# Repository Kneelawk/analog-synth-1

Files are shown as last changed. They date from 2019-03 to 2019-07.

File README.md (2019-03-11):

# analog-synth-1
A simple 1v/oct synth using op-amps

This project is a version of the 1v/oct synth from [DIY Synth Series Part 1 - The Exponential VCO](https://www.allaboutcircuits.com/projects/diy-synth-series-vco/) modified to use the TL084 and to fit into a 12hp module.

In addition this module has a multicolor LED that lights depending on the CV and GATE values.

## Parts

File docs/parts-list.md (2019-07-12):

# Parts List

Some of the parts contained within this project have specific suppliers and specifications.
Here are some of those parts:

* [LED_RCBG](#led_rcbg)
* [PJ398SM](#pj398sm)
* [Conn_02x08_Odd_Even](#conn_02x08_odd_even)

# Part Specifications

## LED_RCBG
Mouser Product URL:
https://www.mouser.com/ProductDetail/Kingbright/WP154A4SUREQBFZGW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

Manufacturer: Kingbright

Datasheet URL:
https://www.mouser.com/datasheet/2/216/WP154A4SUREQBFZGW-67444.pdf

## PJ398SM
### Product Notes
The PJ301M-12 is being discontinued due to some design flaws. Its replacement is the PJ398SM.
The PJ301M-12 has the same footprint as the PJ398SM.

### URLs
Product URL:
https://www.thonk.co.uk/shop/thonkiconn/

## Conn_02x08_Odd_Even
### Product Notes
This jack is the 16-pin shrouded eurorack header.

### URLS
Product URL:
https://store.synthrotek.com/16-Pin_Keyed_Shrouded_Eurorack_Power_Header

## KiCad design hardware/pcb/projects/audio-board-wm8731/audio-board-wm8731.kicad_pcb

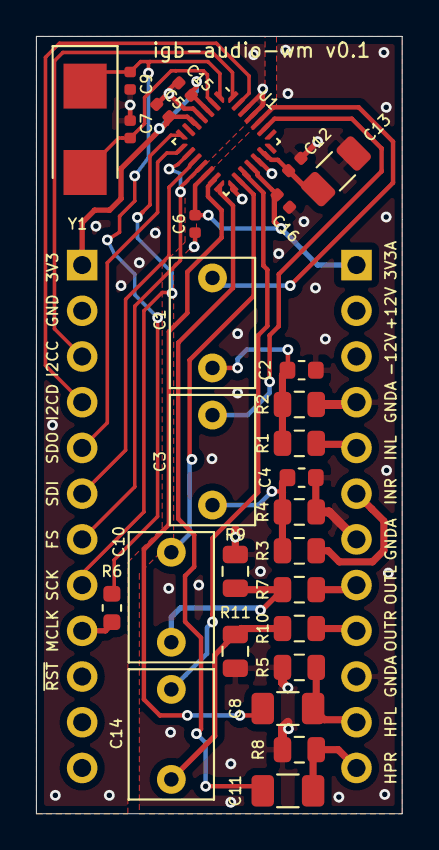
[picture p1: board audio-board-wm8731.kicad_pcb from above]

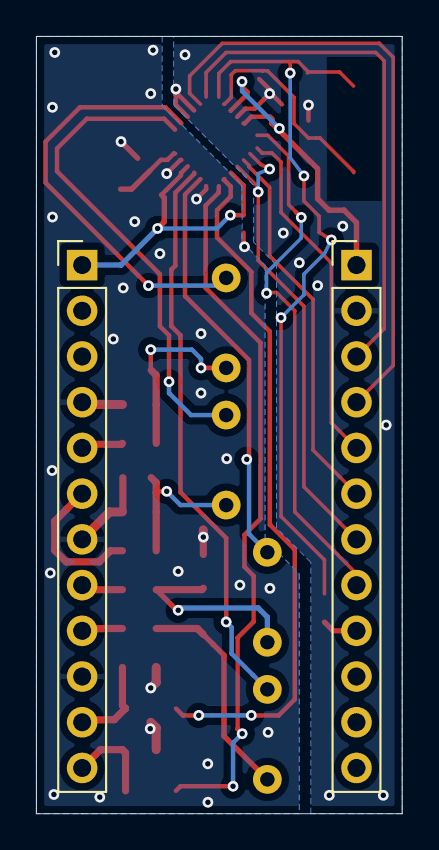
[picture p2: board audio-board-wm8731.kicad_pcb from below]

Board: 2 copper layers, 20.3 x 43.2 mm, 31 parts (2 on the bottom side), 30 nets.

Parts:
C1, C3, C10, C14: 1u; C_Rect_L7.0mm_W4.5mm_P5.00mm
C2, C4: 220p; C_0603_1608Metric
C5, C6, C12, C15, C16: 100n; C_0402_1005Metric
C7, C9: 18p; C_0402_1005Metric
C8, C11: 100u; C_1206_3216Metric
C13: 10u; C_1206_3216Metric
J1, J2: Conn_01x12; PinHeader_1x12_P2.54mm_Vertical
R1, R2, R3, R4: 10k; R_0805_2012Metric
R5, R8, R9, R11: 100k; R_0805_2012Metric
R6: 0; R_0603_1608Metric
R7, R10: 100; R_0805_2012Metric
U1: wm8731_qfn; QFN-28_4x4mm_P0.5mm
Y1: 12.288MHz; Crystal_SMD_Abracon_ABM3-2pin_5.0x3.2mm_hand

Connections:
+3.3VA: C6.2, C16.2, J1.1, U1.12, U1.18
+3V3: C5.2, C15.2, J2.1, U1.3, U1.5
/ADC_L: C1.2, U1.24
/ADC_R: C3.2, U1.23
/DAC_L: C10.2, U1.16
/DAC_R: C14.2, U1.17
/HP_OUT_L: C8.2, J1.11, R5.2
/HP_OUT_R: C11.2, J1.12, R8.2
/I2C_SCL: J2.3, U1.28
/I2C_SDA: J2.4, U1.27
/I2S_FS: J2.7, U1.9, U1.11
/I2S_MCLK: J2.9, R6.1
/I2S_SCK: J2.8, U1.7
/I2S_SDI: J2.6, U1.10
/I2S_SDO: J2.5, U1.8
/LINE_IN_L: J1.5, R1.2
/LINE_IN_R: J1.6, R3.2
/LINE_OUT_L: J1.8, R7.2
/LINE_OUT_R: J1.9, R10.2
GND: C5.1, C7.2, C9.2, C15.1, J2.2, U1.4, U1.25, U1.26
GNDA: C2.1, C4.1, C6.1, C12.2, C13.2, C16.1, J1.4, J1.7, J1.10, R2.2, R4.2, R5.1, R8.1, R9.1, R11.1, U1.15, U1.19
unnamed: C1.1, C2.2, R1.1, R2.1
unnamed: C3.1, C4.2, R3.1, R4.1
unnamed: C7.1, U1.2, Y1.2
unnamed: C8.1, U1.13
unnamed: C9.1, R6.2, U1.1, Y1.1
unnamed: C10.1, R7.1, R9.2
unnamed: C11.1, U1.14
unnamed: C12.1, C13.1, U1.20
unnamed: C14.1, R10.1, R11.2

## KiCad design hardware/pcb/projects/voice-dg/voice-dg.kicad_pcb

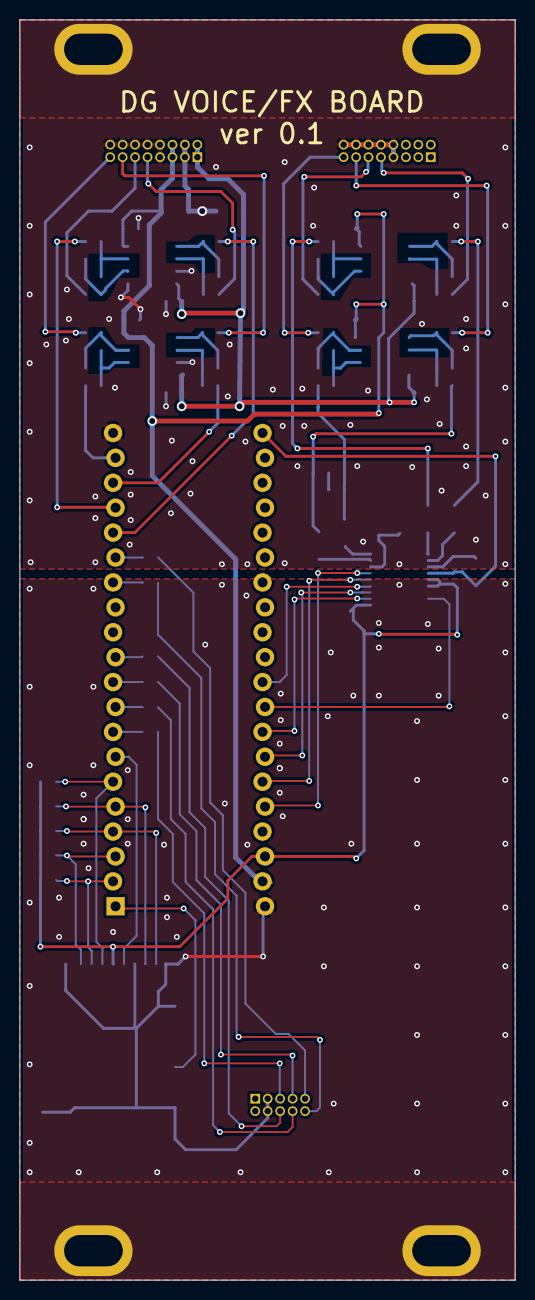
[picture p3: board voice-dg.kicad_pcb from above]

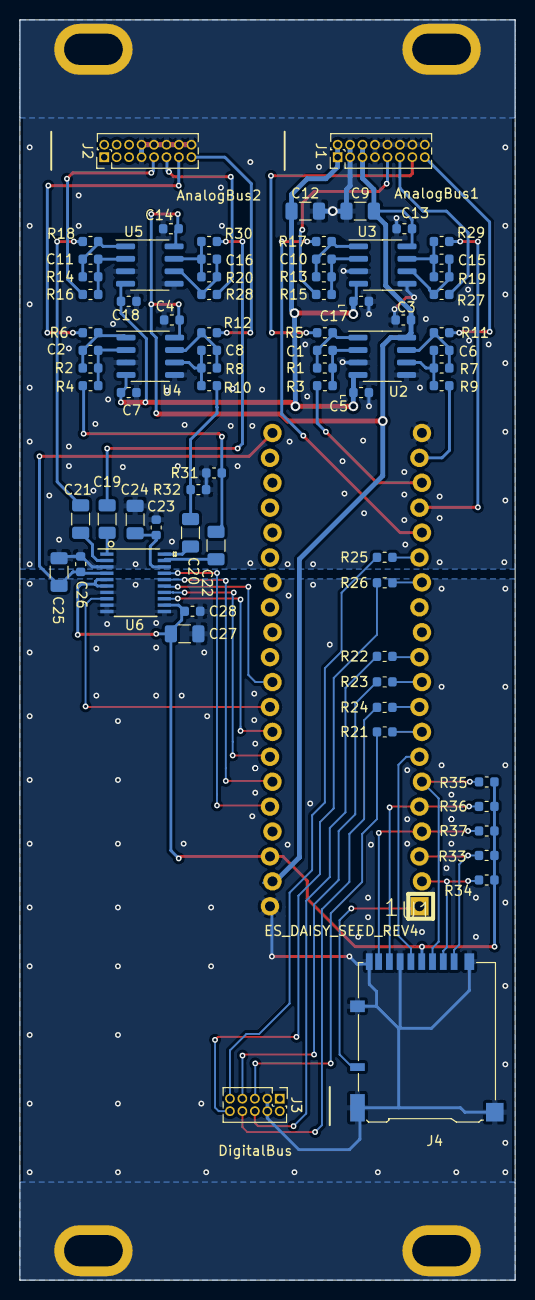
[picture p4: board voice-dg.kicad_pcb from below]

Board: 2 copper layers, 50.5 x 128.5 mm, 75 parts (75 on the bottom side), 68 nets.

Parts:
C1, C2, C6, C8, C10, C11, C15, C16: 12p; C_0603_1608Metric
C3, C4, C5, C7, C13, C14, C17, C18, C23, C26, C28: 100n; C_0603_1608Metric
C9, C12: 22u; C_1206_3216Metric
C19, C20, C21, C22, C25, C27: 10u; C_1206_3216Metric
C24: 2.2u; C_1206_3216Metric
J1: AnalogBus; PinHeader_2x08_P1.27mm_Vertical
J2: AnalogBusEx; PinHeader_2x08_P1.27mm_Vertical
J3: DigitalBus; PinHeader_2x05_P1.27mm_Vertical
J4: Micro_SD_Card_Det_Hirose_DM3AT; microSD_HC_Hirose_DM3AT-SF-PEJM5_hand
R1, R2, R7, R8, R15, R16, R27, R28: 100k; R_0603_1608Metric
R3, R4, R9, R10, R13, R14, R19, R20: 10k; R_0603_1608Metric
R5, R6, R11, R12, R17, R18, R29, R30: 470; R_0603_1608Metric
R21, R22, R23, R24, R25, R26: 47; R_0603_1608Metric
R31, R32, R33, R34, R35, R36, R37: 47k; R_0603_1608Metric
U1: ES_DAISY_SEED_REV4; ES_DAISY_SEED
U2, U3, U4, U5: OPA2134; SOIC-8_3.9x4.9mm_P1.27mm
U6: AK4556VT

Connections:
+3.3VA: C25.2, C26.1, U1.21, U6.4
+3V3: C27.2, C28.1, J4.4, R33.2, R34.2, R35.2, R36.2, R37.2, U1.38, U6.5, U6.6, U6.12
+12V: C3.1, C4.1, C9.2, C13.1, C14.1, J1.5, J1.6, U1.39, U2.8, U3.8, U4.8, U5.8
-12V: C5.1, C7.1, C12.1, C17.1, C18.1, J1.1, J1.2, U2.4, U3.4, U4.4, U5.4
/AK4556_RST: U1.36, U6.17
/AnalogIn1: J1.9, R15.2
/AnalogIn2: J1.11, R27.2
/AnalogIn3: J2.9, R16.2
/AnalogIn4: J2.11, R28.2
/AnalogOut1: J1.13, R5.1
/AnalogOut2: J1.15, R11.1
/AnalogOut3: J2.13, R6.1
/AnalogOut4: J2.15, R12.1
/DG_AUDIO_IN_L: R17.1, U1.16
/DG_AUDIO_IN_R: R29.1, U1.17
/DG_AUDIO_OUT_L: R3.2, U1.18
/DG_AUDIO_OUT_R: R9.2, U1.19
/EX_AUDIO_IN_L: C21.1, R18.1
/EX_AUDIO_IN_R: C19.1, R30.1
/EX_AUDIO_OUT_L: C22.2, R4.2, R31.2
/EX_AUDIO_OUT_R: C20.2, R10.2, R32.2
/SAI2_FS_B: U1.34, U6.14
/SAI2_MCLK_B: U1.31, U6.15
/SAI2_SCK_B: U1.35, U6.16
/SAI2_SD_A: U1.33, U6.13
/SAI2_SD_B: U1.32, U6.8
/SD_CLK: J4.5, U1.7
/SD_CMD: J4.3, R35.1, U1.6
/SD_D0: J4.7, R36.1, U1.5
/SD_D1: J4.8, R37.1, U1.4
/SD_D2: J4.1, R33.1, U1.3
/SD_D3: J4.2, R34.1, U1.2
/SPI_MISO: R23.2, U1.10
/SPI_MOSI: R22.1, U1.11
/SPI_SCK: R24.1, U1.9
/USART_RX: R25.2, U1.15
/USART_TX: R26.1, U1.14
/~SD_SW: J4.10, U1.1
/~SPI_CS: R21.2, U1.8
GND: C27.1, C28.2, J3.3, J3.4, J4.6, J4.9, J4.11, U1.40, U6.7, U6.9, U6.10, U6.11
GNDA: C3.2, C4.2, C5.2, C7.2, C9.1, C12.2, C13.2, C14.2, C17.2, C18.2, C23.2, C24.1, C25.1, C26.2, J1.3, J1.4, J1.7, J1.8, J1.10, J1.12, J1.14, J1.16, J2.7, J2.8, J2.10, J2.12, J2.14, J2.16, R31.1, R32.1, U1.20, U2.3, U2.5, U3.3, U3.5, U4.3, U4.5, U5.3, U5.5, U6.3
unnamed: C1.1, R1.1, R5.2, U2.1
unnamed: C1.2, R1.2, R3.1, U2.2
unnamed: C2.1, R2.1, R6.2, U4.1
unnamed: C2.2, R2.2, R4.1, U4.2
unnamed: C6.1, R7.1, R11.2, U2.7
unnamed: C6.2, R7.2, R9.1, U2.6
unnamed: C8.1, R8.1, R12.2, U4.7
unnamed: C8.2, R8.2, R10.1, U4.6
unnamed: C10.1, R13.1, R17.2, U3.1
unnamed: C10.2, R13.2, R15.1, U3.2
unnamed: C11.1, R14.1, R18.2, U5.1
unnamed: C11.2, R14.2, R16.1, U5.2
unnamed: C15.1, R19.1, R29.2, U3.7
unnamed: C15.2, R19.2, R27.1, U3.6
unnamed: C16.1, R20.1, R30.2, U5.7
unnamed: C16.2, R20.2, R28.1, U5.6
unnamed: C19.2, U6.1
unnamed: C20.1, U6.20
unnamed: C21.2, U6.2
unnamed: C22.1, U6.19
unnamed: C23.1, C24.2, U6.18
unnamed: J3.5, R21.1
unnamed: J3.6, R22.2
unnamed: J3.7, R23.1
unnamed: J3.8, R24.2
unnamed: J3.9, R25.1
unnamed: J3.10, R26.2

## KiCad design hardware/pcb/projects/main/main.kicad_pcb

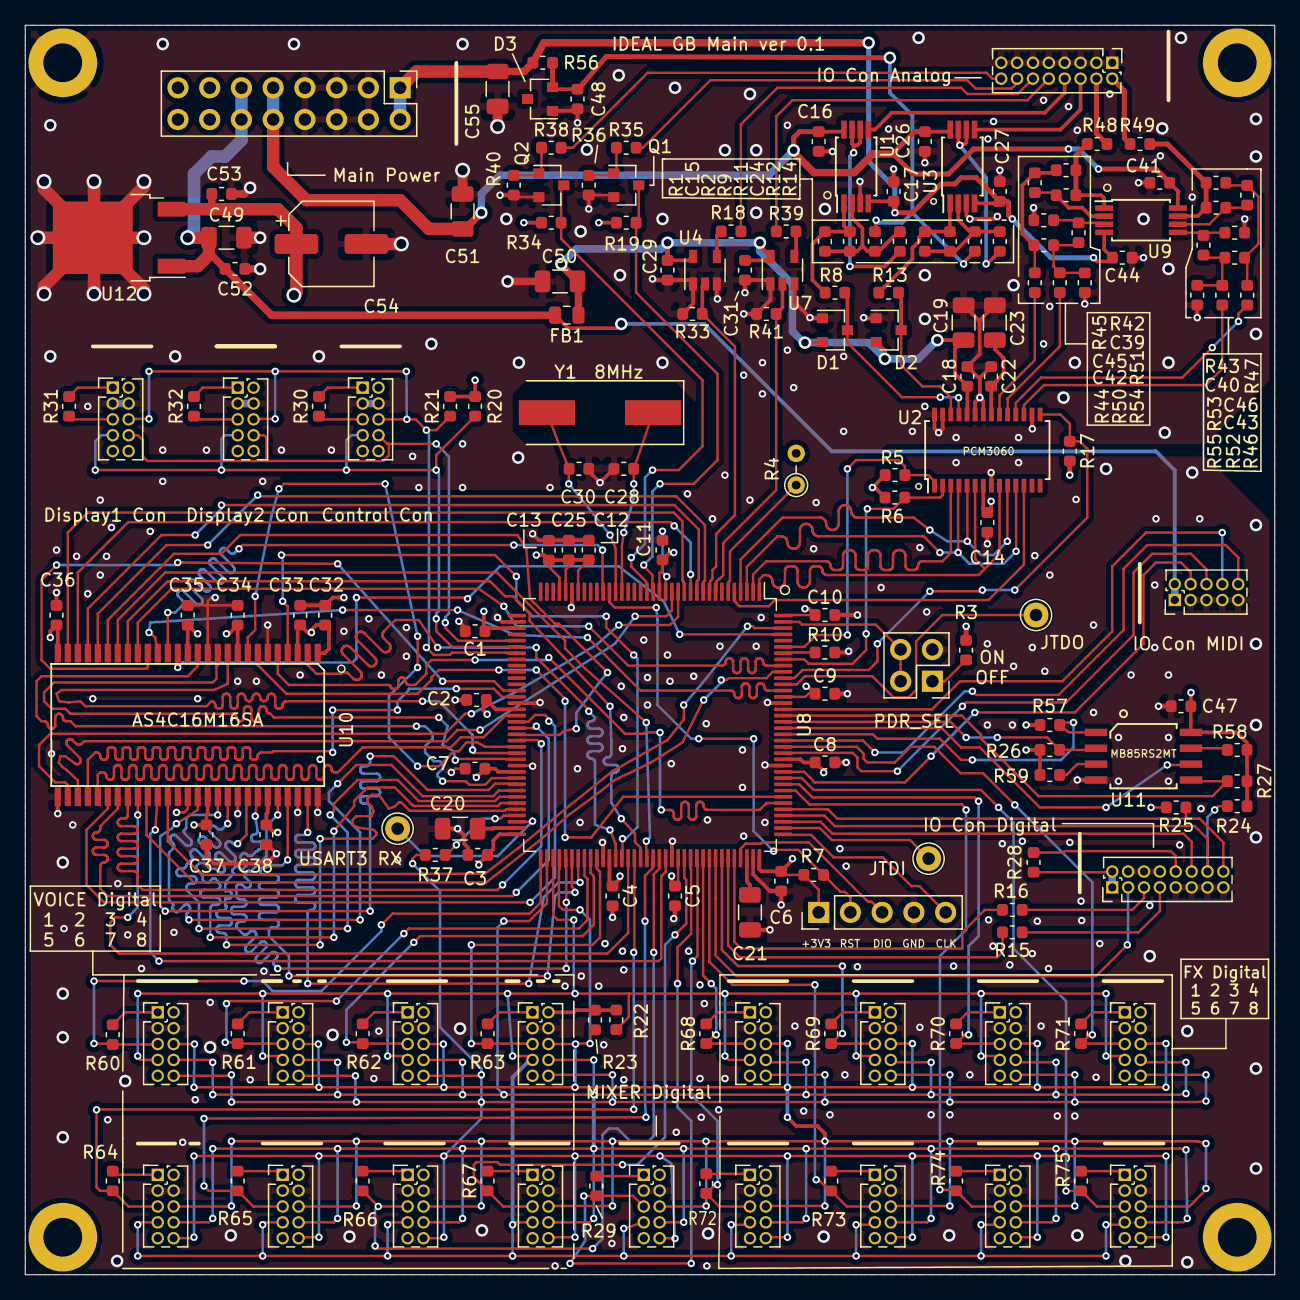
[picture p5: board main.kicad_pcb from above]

Board: 4 copper layers, 100.0 x 100.0 mm, 176 parts (0 on the bottom side), 154 nets.

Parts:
C1, C2, C3, C4, C5, C6, C7, C8, C9, C10, C11, C12, C13, C14, C16, C17, C18, C22, C25, C26, C27, C29, C31, C32, C33, C34, C35, C36, C37, C38, C41, C44, C47, C48, C52, C53: 100n; C_0603_1608Metric
C15, C24, C28, C30: 18p; C_0603_1608Metric
C19, C23: 10u; C_1206_3216Metric
C20, C21: 2.2u; C_1206_3216Metric
C39, C40, C45, C46: 470p; C_0603_1608Metric
C42, C43: 2.2n; C_0603_1608Metric
C49, C50, C51, C55: 22u; C_1206_3216Metric
C54: 100u; CP_Elec_6.3x5.3
D1, D2: BAT54S; SOT-23
D3: LM4040; SOT-23
FB1: Ferrite; R_0805_2012Metric
J1: IO_CON_ANALOG; PinHeader_2x08_P1.27mm_Vertical
J2: PDR_ON_SEL; PinHeader_2x02_P2.54mm_Vertical
J3: VOICE1_DIGITAL; PinHeader_2x05_P1.27mm_Vertical
J4: FX1_DIGITAL; PinHeader_2x05_P1.27mm_Vertical
J5: VOICE5_DIGITAL; PinHeader_2x05_P1.27mm_Vertical
J6: FX5_DIGITAL; PinHeader_2x05_P1.27mm_Vertical
J7: VOICE2_DIGITAL; PinHeader_2x05_P1.27mm_Vertical
J8: FX2_DIGITAL; PinHeader_2x05_P1.27mm_Vertical
J9: VOICE6_DIGITAL; PinHeader_2x05_P1.27mm_Vertical
J10: FX6_DIGITAL; PinHeader_2x05_P1.27mm_Vertical
J11: VOICE3_DIGITAL; PinHeader_2x05_P1.27mm_Vertical
J12: FX3_DIGITAL; PinHeader_2x05_P1.27mm_Vertical
J13: VOICE7_DIGITAL; PinHeader_2x05_P1.27mm_Vertical
J14: FX7_DIGITAL; PinHeader_2x05_P1.27mm_Vertical
J15: IO_CON_MIDI; PinHeader_2x05_P1.27mm_Vertical
J16: VOICE4_DIGITAL; PinHeader_2x05_P1.27mm_Vertical
J17: FX4_DIGITAL; PinHeader_2x05_P1.27mm_Vertical
J18: VOICE8_DIGITAL; PinHeader_2x05_P1.27mm_Vertical
J19: FX8_DIGITAL; PinHeader_2x05_P1.27mm_Vertical
J20: SWD_CON; PinHeader_1x05_P2.54mm_Vertical
J21: MIXER_DIGITAL; PinHeader_2x05_P1.27mm_Vertical
J22: DISPLAY1_DIGITAL; PinHeader_2x05_P1.27mm_Vertical
J23: IO_CON_DIGITAL; PinHeader_2x08_P1.27mm_Vertical
J24: POWER_CON; PinHeader_2x08_P2.54mm_Vertical
J25: CONTROL_DIGTAL; PinHeader_2x05_P1.27mm_Vertical
J26: DISPLAY2_DIGITAL; PinHeader_2x05_P1.27mm_Vertical
Q1, Q2: MMBT3904; SOT-23
R1, R11: 30k; R_0603_1608Metric
R2, R12: 120k; R_0603_1608Metric
R3, R5, R6, R7, R10, R17, R19, R20, R21, R22, R23, R24, R25, R26, R27, R28, R29, R30, R31, R32, R33, R34, R41, R57, R58, R59, R60, R61, R62, R63, R64, R65, R66, R67, R68, R69, R70, R71, R72, R73, R74, R75: 10k; R_0603_1608Metric
R4: 0; R_Axial_DIN0204_L3.6mm_D1.6mm_P2.54mm_Vertical
R8, R13, R48, R49: 470; R_0603_1608Metric
R9, R14: 200k; R_0603_1608Metric
R15, R16, R37: 10; R_0603_1608Metric
R18, R39, R45, R47, R51, R53: 1k; R_0603_1608Metric
R35, R36, R38, R40: 100k; R_0603_1608Metric
R42, R43, R54, R55: 12k; R_0603_1608Metric
R44, R46, R50, R52: 4.7k; R_0603_1608Metric
R56: 3.3k; R_0603_1608Metric
TP1: JTDI; Pin_D1.0mm_L10.0mm
TP2: JTDO; Pin_D1.0mm_L10.0mm
TP3: USART3_RX; Pin_D1.0mm_L10.0mm
U1, U3, U9: TL072; TSSOP-8_4.4x3mm_P0.65mm
U2: PCM3060; TSSOP-28_4.4x9.7mm_P0.65mm
U4, U7: 74AHCT1G125; SOT-23-5
U8: STM32F446ZETx; LQFP-144_20x20mm_P0.5mm
U10: AS4C16M16SA
U11: MB85RS2MT
U12: L7803; TO-252-2
Y1: 8MHz; Crystal_SMD_HC49-SD

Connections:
+3V3: C1.1, C2.1, C3.1, C4.1, C5.1, C6.1, C7.1, C8.1, C9.1, C10.1, C11.1, C12.1, C13.1, C14.1, C25.1, C32.1, C33.1, C34.1, C35.1, C36.1, C37.1, C38.1, C47.2, C53.1, C54.1, J3.1, J3.2, J4.1, J4.2, J5.1, J5.2, J6.1, J6.2, J7.1, J7.2, J8.1, J8.2, J9.1, J9.2, J10.1, J10.2, J11.1, J11.2, J12.1, J12.2, J13.1, J13.2, J14.1, J14.2, J16.1, J16.2, J17.1, J17.2, J18.1, J18.2, J19.1, J19.2, J20.1, J21.1, J21.2, J22.1, J22.2, J23.1, J23.2, J25.1, J25.2, J26.1, J26.2, R3.2, R4.2, R5.2, R6.2, R7.2, R17.2, R19.1, R20.2, R21.2, R22.2, R23.2, R24.2, R25.2, R26.2, R27.2, R28.2, R29.2, R30.2, R31.2, R32.2, R34.1, R57.2, R58.2, R59.2, R60.2, R61.2, R62.2, R63.2, R64.2, R65.2, R66.2, R67.2, R68.2, R69.2, R70.2, R71.2, R72.2, R73.2, R74.2, R75.2, U2.7, U8.17, U8.30, U8.32, U8.33, U8.39, U8.52, U8.62, U8.72, U8.84, U8.95, U8.108, U8.121, U8.131, U8.144, U10.1, U10.3, U10.9, U10.14, U10.27, U10.43, U10.49, U11.8, U12.3
+5V: C49.1, C52.1, FB1.2, J15.1, J15.2, J24.11, J24.12, U12.1
+5VA: C18.1, C19.1, C29.1, C31.1, C50.1, D1.2, D2.2, FB1.1, U2.24, U4.5, U7.5
+12V: C16.1, C26.1, C41.1, C51.1, J24.9, J24.10, U1.8, U3.8, U9.8
-12V: C17.2, C27.2, C44.2, C55.2, J24.1, J24.2, R56.2, U1.4, U3.4, U9.4
/FMC_A0: U8.10, U10.23
/FMC_A1: U8.11, U10.24
/FMC_A2: U8.12, U10.25
/FMC_A3: U8.13, U10.26
/FMC_A4: U8.14, U10.29
/FMC_A5: U8.15, U10.30
/FMC_A6: U8.50, U10.31
/FMC_A7: U8.53, U10.32
/FMC_A8: U8.54, U10.33
/FMC_A9: U8.55, U10.34
/FMC_A10: U8.56, U10.22
/FMC_A11: U8.57, U10.35
/FMC_A12: U8.87, U10.36
/FMC_BA0: U8.89, U10.20
/FMC_BA1: U8.90, U10.21
/FMC_D0: U8.85, U10.2
/FMC_D1: U8.86, U10.4
/FMC_D2: U8.114, U10.5
/FMC_D3: U8.115, U10.7
/FMC_D4: U8.58, U10.8
/FMC_D5: U8.59, U10.10
/FMC_D6: U8.60, U10.11
/FMC_D7: U8.63, U10.13
/FMC_D8: U8.64, U10.42
/FMC_D9: U8.65, U10.44
/FMC_D10: U8.66, U10.45
/FMC_D11: U8.67, U10.47
/FMC_D12: U8.68, U10.48
/FMC_D13: U8.77, U10.50
/FMC_D14: U8.78, U10.51
/FMC_D15: U8.79, U10.53
/FMC_NBL0: U8.141, U10.15
/FMC_NBL1: U8.142, U10.39
/FMC_SDCKE1: U8.135, U10.37
/FMC_SDCLK: U8.93, U10.38
/FMC_SDNCAS: U8.132, U10.17
/FMC_SDNE1: U8.136, U10.19
/FMC_SDNRAS: U8.49, U10.18
/FMC_SDNWE: U8.26, U10.16
/I2C_SCL: R5.1, U2.1, U8.139
/I2C_SDA: R6.1, U2.2, U8.137
/OTG_FS_DM: J23.7, R15.1
/OTG_FS_DP: J23.5, R16.1
/OTG_FS_VBUS: J23.3, U8.101
/SAI1_FS_A: U2.4, U2.11, U8.3
/SAI1_MCLK_A: U2.6, U2.9, U8.1
/SAI1_SCK_A: U2.5, U2.10, U8.4
/SAI1_SD_A: U2.12, U8.5
/SAI1_SD_B: U2.3, U8.2
/SPI1_MISO: J22.7, J25.7, J26.7, R20.1, U8.42
/SPI1_MOSI: J22.6, J25.6, J26.6, R21.1, U8.43
/SPI1_SCK: J22.8, J25.8, J26.8, U8.41
/SPI2_MISO: J3.7, J4.7, J5.7, J6.7, J7.7, J8.7, J9.7, J10.7, J11.7, J12.7, J13.7, J14.7, J16.7, J17.7, J18.7, J19.7, J21.7, R22.1, U8.75
/SPI2_MOSI: J3.6, J4.6, J5.6, J6.6, J7.6, J8.6, J9.6, J10.6, J11.6, J12.6, J13.6, J14.6, J16.6, J17.6, J18.6, J19.6, J21.6, R23.1, U8.76
/SPI2_SCK: J3.8, J4.8, J5.8, J6.8, J7.8, J8.8, J9.8, J10.8, J11.8, J12.8, J13.8, J14.8, J16.8, J17.8, J18.8, J19.8, J21.8, U8.74
/SPI3_MISO: J23.14, R24.1, U8.112
/SPI3_MOSI: J23.16, R25.1, U8.113
/SPI3_SCK: J23.12, U8.111
/SPI4_MISO: R26.1, U8.127, U11.2
/SPI4_MOSI: R27.1, U8.128, U11.5
/SPI4_SCK: U8.126, U11.6
/SWCLK: J20.5, U8.109
/SWDIO: J20.3, U8.105
/USART2_RX: J15.6, U8.122
/USART2_TX: J15.4, U8.119
/USART3_TX: J3.10, J4.10, J5.10, J6.10, J7.10, J8.10, J9.10, J10.10, J11.10, J12.10, J13.10, J14.10, J16.10, J17.10, J18.10, J19.10, J21.10, R37.1
/USART6_RX: J15.10, U8.124
/USART6_TX: J15.8, U8.129
/~CONTROL_SPI_CS: J25.5, R30.1
/~DAC_RESET: R17.1, U2.15, U8.134
/~DISPLAY1_SPI_CS: J22.5, R31.1
/~DISPLAY2_SPI_CS: J26.5, R32.1
/~FRAM_SPI_CS: R57.1, U8.125, U11.1
/~FX1_SPI_CS: J4.5, R68.1, U8.99
/~FX2_SPI_CS: J8.5, R69.1, U8.102
/~FX3_SPI_CS: J12.5, R70.1, U8.117
/~FX4_SPI_CS: J17.5, R71.1, U8.123
/~FX5_SPI_CS: J6.5, R72.1, U8.98
/~FX6_SPI_CS: J10.5, R73.1, U8.100
/~FX7_SPI_CS: J14.5, R74.1, U8.116
/~FX8_SPI_CS: J19.5, R75.1, U8.118
/~MIXER_SPI_CS: J21.5, R29.1, U8.97
/~RESET: J20.2, R7.1, U8.25
/~SD_SPI_CS: J23.10, R28.1
/~VOICE1_SPI_CS: J3.5, R60.1, U8.73
/~VOICE2_SPI_CS: J7.5, R61.1, U8.80
/~VOICE3_SPI_CS: J11.5, R62.1, U8.81
/~VOICE4_SPI_CS: J16.5, R63.1, U8.82
/~VOICE5_SPI_CS: J5.5, R64.1, U8.88
/~VOICE6_SPI_CS: J9.5, R65.1, U8.91
/~VOICE7_SPI_CS: J13.5, R66.1, U8.92
/~VOICE8_SPI_CS: J18.5, R67.1, U8.96
CV1_IN: J1.8, U1.5
CV1_OUT: J1.4, R48.2
CV2_IN: J1.6, U3.5
CV2_OUT: J1.2, R49.2
DAC_IN_L: D1.3, R8.1, U2.25
DAC_IN_R: D2.3, R13.1, U2.26
DAC_VOUTL+: R44.1, U2.20
DAC_VOUTL-: R50.1, U2.19
DAC_VOUTR+: R46.1, U2.18
DAC_VOUTR-: R52.1, U2.17
GATE1_IN: J1.16, R38.2
GATE1_IN_BUF_OUT: Q2.3, R34.2, U8.19
GATE1_OUT: J1.12, R18.1
GATE1_OUT_BUF_IN: R33.1, U4.2, U8.9
GATE2_IN: J1.14, R35.2
GATE2_IN_BUF_OUT: Q1.3, R19.2, U8.18
GATE2_OUT: J1.10, R39.1
GATE2_OUT_BUF_IN: R41.1, U7.2, U8.8
GND: C1.2, C2.2, C3.2, C4.2, C5.2, C6.2, C7.2, C8.2, C9.2, C10.2, C11.2, C12.2, C13.2, C14.2, C16.2, C17.1, C18.2, C19.2, C20.2, C21.2, C22.1, C23.1, C25.2, C26.2, C27.1, C28.2, C29.2, C30.2, C31.2, C32.2, C33.2, C34.2, C35.2, C36.2, C37.2, C38.2, C41.2, C44.1, C45.1, C46.1, C47.1, C48.2, C49.2, C50.2, C51.2, C52.2, C53.2, C54.2, C55.1, D1.1, D2.1, D3.1, J1.1, J1.3, J1.5, J1.7, J1.9, J1.11, J1.13, J1.15, J2.3, J3.3, J3.4, J4.3, J4.4, J5.3, J5.4, J6.3, J6.4, J7.3, J7.4, J8.3, J8.4, J9.3, J9.4, J10.3, J10.4, J11.3, J11.4, J12.3, J12.4, J13.3, J13.4, J14.3, J14.4, J15.3, J15.5, J15.7, J15.9, J16.3, J16.4, J17.3, J17.4, J18.3, J18.4, J19.3, J19.4, J20.4, J21.3, J21.4, J22.3, J22.4, J23.4, J23.6, J23.8, J23.9, J23.11, J23.13, J23.15, J24.3, J24.4, J24.5, J24.6, J24.7, J24.8, J25.3, J25.4, J26.3, J26.4, Q1.2, Q2.2, R10.2, R33.2, R36.2, R40.2, R41.2, R54.1, R55.1, U1.3, U2.8, U2.16, U2.22, U2.23, U2.27, U2.28, U3.3, U4.1, U4.3, U7.1, U7.3, U8.16, U8.31, U8.38, U8.51, U8.61, U8.83, U8.94, U8.107, U8.120, U8.130, U10.6, U10.12, U10.28, U10.41, U10.46, U10.52, U10.54, U11.4, U12.2
unnamed: C15.1, R1.2, R2.1, R9.1, U1.2
unnamed: C15.2, R1.1, R8.2, U1.1
unnamed: C20.1, U8.71
unnamed: C21.1, U8.106
unnamed: C22.2, C23.2, U2.21
unnamed: C24.1, R11.2, R12.1, R14.1, U3.2
unnamed: C24.2, R11.1, R13.2, U3.1
unnamed: C28.1, U8.23, Y1.1
unnamed: C30.1, U8.24, Y1.2
unnamed: C39.1, R45.2, U9.2
unnamed: C39.2, R42.2, R48.1, U9.1
unnamed: C40.1, R47.2, U9.6
unnamed: C40.2, R43.2, R49.1, U9.7
unnamed: C42.1, R42.1, R44.2, R45.1
unnamed: C42.2, R50.2, R51.1, R54.2
unnamed: C43.1, R43.1, R46.2, R47.1
unnamed: C43.2, R52.2, R53.1, R55.2
unnamed: C45.2, R51.2, U9.3
unnamed: C46.2, R53.2, U9.5
unnamed: J2.1, R3.1
unnamed: J2.2, J2.4, U8.143
unnamed: Q1.1, R35.1, R36.1
unnamed: Q2.1, R38.1, R40.1
unnamed: R4.1, U8.6
unnamed: R9.2, U1.6, U1.7
unnamed: R10.1, U8.138
unnamed: R14.2, U3.6, U3.7
unnamed: R15.2, U8.103
unnamed: R16.2, U8.104
unnamed: R18.2, U4.4
unnamed: R37.2, U8.69
unnamed: R39.2, U7.4
unnamed: R58.1, U11.7
unnamed: R59.1, U11.3
unnamed: TP1.1, U8.110
unnamed: TP2.1, U8.133
unnamed: TP3.1, U8.70
VREF_-10V: C48.1, D3.2, R2.2, R12.2, R56.1

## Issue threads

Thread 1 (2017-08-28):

Transistors may be too tall to fit on the top side of the PCB

Kneelawk, 2017-08-28:
The transistors (especially the thermocoupled transistors) are likely too tall (taller than 10cm) to fit between the circuit board and the front panel. The transistors should be moved to the back side.

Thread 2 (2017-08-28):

LED light for each module

Kneelawk, 2017-08-28:
It might be possible to fit an ATtiny85 and an RGB LED on the pcb so that the LED will light up when the synth plays a note and the led's color depends on the note being played.

Kneelawk, 2017-08-28:
This may only fit on the LM324 version of the board.

Kneelawk, 2019-03-16:
The board has been redesigned to use TL084s instead of 741s. This will hopefully give enough space for the ATtiny85. The circuit diagram has been updated to include the ATtiny85.

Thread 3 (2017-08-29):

Over-voltage and over-current protection

Kneelawk, 2017-08-29:
The synth currently has no voltage protection: sending a CV or Gate signal over 5 volts or under 0 volts could cause damage to the synth.
The synth currentlu has no current protection: drawing too much current from an output, shorting it to any supply rail, or plugging two outputs into each other could cause damage to the synth.

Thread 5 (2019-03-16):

ATtiny85 CV input is unprotected from high voltages.

Kneelawk, 2019-03-16:
The CV input to the ATtiny85 LED controller is powered by an op amp that is powered from a +-12V supply. This +-12V supply is necessary for the op-amp because its output cannot swing all the way to its supply rails, but this does mean that its output can go above +5V or below 0V. If the CV input to the ATtiny85 goes above +5V or below 0V, it could damage the ATtiny85.

Closed 2019-03-30.

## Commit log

2017-08-10 All the files rev1.0.7
    [analog-synth-1.kicad_pcb, analog-synth-1.sch]
2017-08-10 Change vco tuning system
    [analog-synth-1.sch]
2017-08-10 Move some wires around
    [analog-synth-1.sch]
2017-08-14 Add footprints and fix pin header orientation
    [analog-synth-1.sch]
2017-08-14 Change trimmer descriptions and plot pdf
    [analog-synth-1.sch]
2017-08-15 Use PJ301M-12 3.3mm jacks
    [analog-synth-1.sch]
2017-08-15 Update schematic libs, add Gate jack
    [analog-synth-1.sch]
2017-08-15 Use RK09L potentiometer
    [analog-synth-1.sch]
2017-08-17 Begin on PCB
    [analog-synth-1.sch]
2017-08-17 Finish PCB
    [analog-synth-1.kicad_pcb]
2017-08-22 Fix VCO tuning rev1.0.13
    [analog-synth-1.kicad_pcb, analog-synth-1.sch]
2017-08-23 Fix polarized capacitor footprints rev1.0.14
    [analog-synth-1.kicad_pcb, analog-synth-1.sch]
2019-02-11 Update Kicad to 5.0.2
2019-03-12 Begin working on ports
    [analog-synth-1-ports.sch, analog-synth-1.sch]
2019-03-12 Add jacks
    [analog-synth-1-ports.sch]
2019-03-12 Add opamp buffers
    [analog-synth-1-ports.sch]
2019-03-12 Add CV input amp
    [analog-synth-1-ports.sch]
2019-03-14 Finish basic synth circuit diagram
    [analog-synth-1-converter.sch, analog-synth-1-led.sch, analog-synth-1-ports.sch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]
2019-03-14 Annotate components
    [analog-synth-1-converter.sch, analog-synth-1-led.sch, analog-synth-1-ports.sch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]
2019-03-30 Add ATtiny85 overdrive protection, fix #5
    [analog-synth-1-converter.sch, analog-synth-1-led.sch, analog-synth-1-ports.sch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]
2019-07-11 Separate synth ports and logic into different boards
    [analog-synth-1-converter.sch, analog-synth-1-led.sch, analog-synth-1-logic-board.kicad_pcb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]
2019-07-11 Build port board schematics
2019-07-11 Switch from RABG to RCBG LED
    [analog-synth-1-port-board.sch]
2019-07-11 Replace PJ301M-12 with PJ398SM
    [analog-synth-1-port-board.sch]
2019-07-12 Fix port board cache library
2019-07-12 Add CV offset & scale system
    [analog-synth-1-port-board.sch]
